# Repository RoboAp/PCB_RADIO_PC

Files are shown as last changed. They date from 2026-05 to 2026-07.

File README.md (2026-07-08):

# VSSS Communication Base - RASPBERRY PI PICO & NRF24L01 🛰️

Este repositório contém o projeto de hardware (PCB) da base emissora/receptora desenvolvida para a equipe **roboAp (UTFPR - Apucarana)**. O módulo é responsável pelo link de comunicação entre a estação de processamento (PC) e os robôs da categoria **Very Small Size Soccer (VSSS)**.

## 📋 Visão Geral

A placa atua como um dongle USB de alto desempenho. Ela utiliza o processamento do **RP2350** para gerenciar o tráfego de dados e o rádio **NRF24L01** para a transmissão em tempo real, garantindo baixa latência nos comandos de trajetória.

## 🛠 Especificações de Hardware

* **Microcontrolador:** PI PICO 2 RP2350
* **Transceptor:** NRF24L01+ (2.4 GHz)
* **Alimentação:** Barramento USB (5V)
* **Interface:** Serial-to-SPI Bridge

## 📐 Destaques do Design (Layout & RF)

O projeto foca na integridade do sinal e na redução de ruído eletromagnético (EMI), considerando o ambiente crítico de competições:

* **RF Overhang (Antena em Balanço):** O conector do NRF24L01 foi posicionado na borda da PCB com o transceptor em balanço (*overhanging*). Isso projeta a antena para fora da área da placa, eliminando a absorção de sinal pelo plano de cobre.
* **Isolamento de Camadas:** Roteamento de sinais e trilhas de alimentação realizado na camada inferior (**B.Cu**), mantendo o módulo de rádio na camada superior (**F.Cu**) para minimizar o acoplamento parasita.
* **Filtragem de Transientes:** Preparada para a inclusão de capacitores de desacoplamento (**100nF cerâmico** e **10µF eletrolítico**) próximos aos pinos de alimentação do NRF. Essencial para estabilizar os picos de corrente durante a transmissão.
* **EMC Optimization:** Firmware configurado para desativar os rádios internos do ESP32 (WiFi/Bluetooth), focando os recursos de energia e processamento exclusivamente no protocolo SPI do rádio externo.

## 📂 Estrutura do Repositório

* `/Hardware`: Arquivos de projeto da PCB (KiCad/EasyEDA), Esquema Elétrico e Gerbers.
* `/Firmware`: Código fonte para a ponte serial e configuração de baixa latência do NRF24L01.
* `/Docs`: Relatórios de testes de bancada e medições de performance.

## 🔧 Configuração e Uso

1. **Firmware:** Ao carregar o código, certifique-se de utilizar `WiFi.mode(WIFI_OFF)` para garantir a estabilidade do link de RF.
2. **Conexão:** Plugue via USB e utilize o terminal (ou software de estratégia) para enviar os comandos via porta Serial.
3. **Hardware:** Recomendado o uso de capacitores de filtro se a comunicação apresentar perda de pacotes (*Packet Loss*) em distâncias superiores a 2 metros.

## 👥 Créditos

* **Desenvolvedor:** Michel Rochytor Lima Barbosa
* **Instituição:** UTFPR - Campus Apucarana
* **Equipe:** [roboAp - Robotics Team](https://github.com/roboap)

---
Projeto desenvolvido sob licença MIT.

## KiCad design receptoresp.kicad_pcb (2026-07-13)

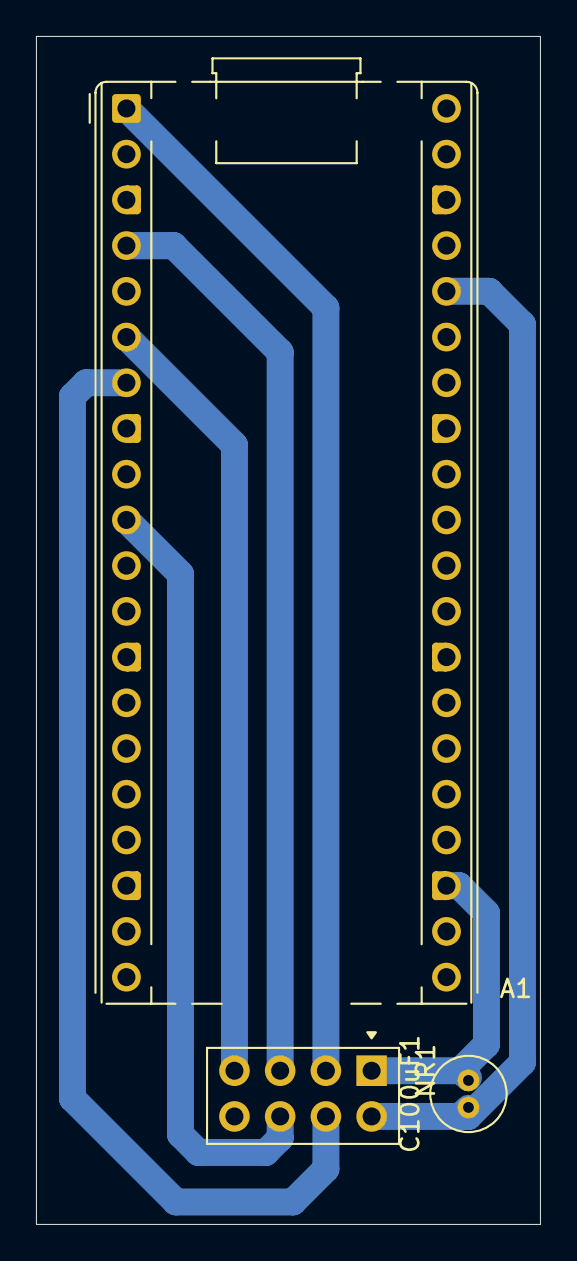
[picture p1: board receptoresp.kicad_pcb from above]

Board: 2 copper layers, 28.0 x 66.0 mm, 3 parts (0 on the bottom side), 7 nets.

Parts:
A1: RaspberryPi_Pico; RaspberryPi_Pico_Common_THT
C100uF1: C_Polarized; C_Radial_D4.0mm_H5.0mm_P1.50mm
NR1: NRF24L01; nRF24L01_Breakout

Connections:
unnamed: A1.36 (3V3), C100uF1.1, NR1.2 (VCC)
unnamed: A1.1 (GPIO0), NR1.3 (CE)
unnamed: A1.4 (GPIO2), NR1.5 (SCK)
unnamed: A1.6 (GPIO4), NR1.7 (MIS0)
unnamed: A1.7 (GPIO5), NR1.4 (CSN)
unnamed: A1.10 (GPIO7), NR1.6 (MOSI)
unnamed: A1.3 (GND), A1.8 (GND), A1.13 (GND), A1.18 (GND), A1.23 (GND), A1.28 (GND), A1.38 (GND), C100uF1.2, NR1.1 (GND)

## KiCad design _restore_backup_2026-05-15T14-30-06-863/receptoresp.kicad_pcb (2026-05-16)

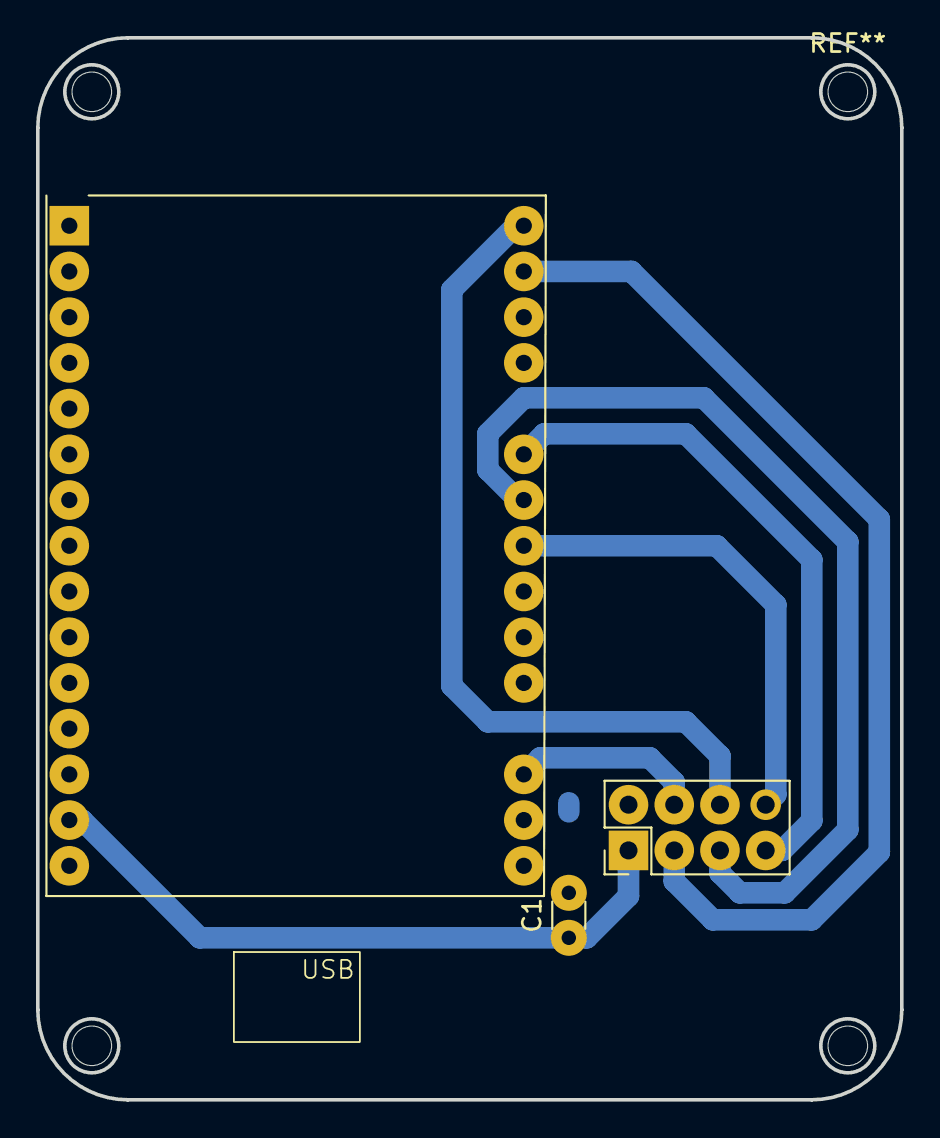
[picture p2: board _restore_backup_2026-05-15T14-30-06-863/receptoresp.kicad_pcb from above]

Board: 2 copper layers, 48.0 x 59.0 mm, 3 parts (0 on the bottom side), 9 nets.

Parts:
C1: C; C_Disc_D3.0mm_W1.6mm_P2.50mm
E1: ESP-WROOM-32
NR1: NRF24L01

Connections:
unnamed: C1.1, E1.16 (3V3)
unnamed: E1.23 (D5), NR1.8 (IRQ)
unnamed: E1.18 (D15), NR1.4 (CSN)
unnamed: E1.24 (D18), NR1.5 (SCK)
unnamed: E1.25 (D19), NR1.7 (MIS0)
unnamed: E1.29 (D22), NR1.3 (CE)
unnamed: E1.30 (D23), NR1.6 (MOSI)
unnamed: E1.14 (GND), NR1.1 (GND)
unnamed: C1.2, NR1.2 (VCC)

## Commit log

2026-05-11 PCB sem capacitor -_-
    [receptoresp.kicad_pcb, receptoresp.kicad_sch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]
2026-05-14 capacitor colocado para o modulo nrf
    [receptoresp.kicad_pcb, receptoresp.kicad_sch]
2026-05-16 capacitor polalizado 100uF
    [receptoresp.kicad_pcb, receptoresp.kicad_sch]
2026-07-08 Change hardware platform from ESP32 to Raspberry Pi Pico
    Updated README to reflect changes in hardware platform from ESP32 to Raspberry Pi Pico.
2026-07-08 pcb pi pico
    [receptoresp.kicad_pcb, receptoresp.kicad_sch]
2026-07-13 one face
    [receptoresp.kicad_pcb, receptoresp.kicad_sch]
